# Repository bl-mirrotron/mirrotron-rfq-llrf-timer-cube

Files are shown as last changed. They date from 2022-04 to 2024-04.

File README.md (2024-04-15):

# RFQ LLRF Timer Cube
* <a href="https://github.com/bl-mirrotron/mirrotron-rfq-llrf-timer-cube" target="_blank">Source code</a>
* [RF frequency source](https://bl-mirrotron.github.io/mirrotron-rf-src-tray/)
* [Gate generator](https://bl-mirrotron.github.io/gateGen125-tray/)
* [Timing system overview](https://bl-mirrotron.github.io/#timing-system)
* [Control system overview](https://bl-mirrotron.github.io/)

The RFQ LLRF Timer Cube is a circuit card that mounts onto header connectors of a <a href="https://redpitaya.com/product-category/stemlab-125-14/" target="_blank">Red Pitaya Stemlab 125-14</a> computer  as shown in Figure 1.  The circuit is used both for the <a href="https://bl-mirrotron.github.io/mirrotron-rf-src-tray/">RF Frequency Source</a> and the <a href="https://bl-mirrotron.github.io/gateGen125-tray/">Gate Generator</a> for the <a href="https://bl-mirrotron.github.io/#timing-system">Timing system</a>. The card contains two systems that can be used independently.

The first system connects a <a href="https://www.mikroe.com/pll-click" target="_blank">PLL Click</a> 8x Phase Lock Loop card that is used by the RF Frequency Source to multiply the 12.5 MHz Direct Digital Synthesizer signal from the Red Pitaya Stemlab 125-14 to 100 MHz.

The second system generates TTL level signals from the Red Pitaya Stemlab 125-14 FPGA digital output pin header to eight SMA RF connectors for the Gate Generator  used in the Timing system.

The circuit also provides 5V and 3.3V output from the Red Pitaya Stemlab 125-14 that can be used to power auxiliary devices such as micro-fans or low noise amplifiers.

The schematic for the card is shown in Figure 2 and the PCB layout is shown in Figure 3.

<p style="text-align:center;font-size: large;"><span style="font-weight: bold;color: green;">Figure 1. </span> <span style="font-style: italic;">RFQ LLRF Timer Cube mounted on a Red Pitaya Stemlab 125-14</span></p>
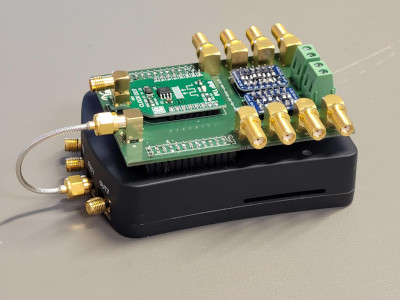
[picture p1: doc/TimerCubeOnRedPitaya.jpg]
<br>

<p style="text-align:center;font-size: large;"><span style="font-weight: bold;color: green;">Figure 2. </span> <span style="font-style: italic;">RFQ LLRF Timer Cube Schematic</span></p>
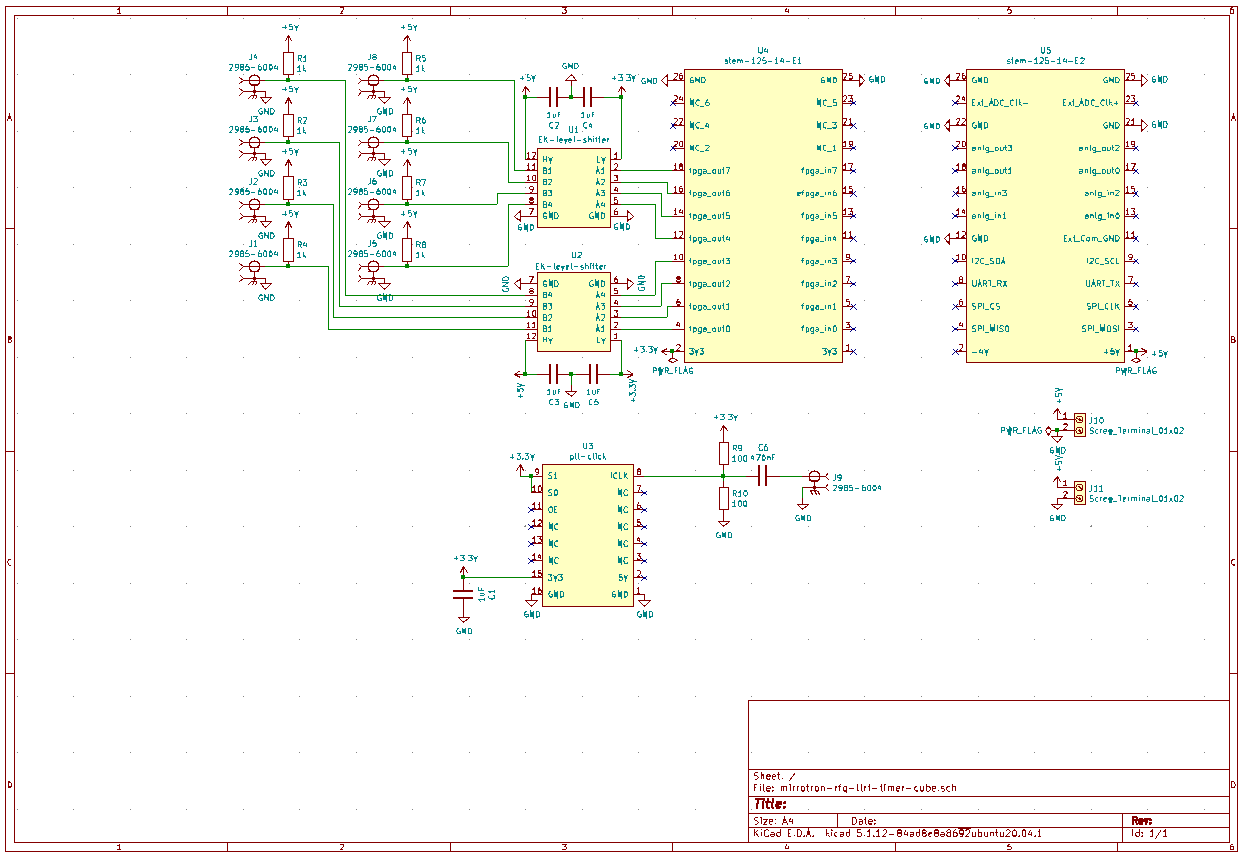
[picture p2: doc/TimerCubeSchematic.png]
<br>

<p style="text-align:center;font-size: large;"><span style="font-weight: bold;color: green;">Figure 3. </span> <span style="font-style: italic;">RFQ LLRF Timer Cube PCB layout</span></p>
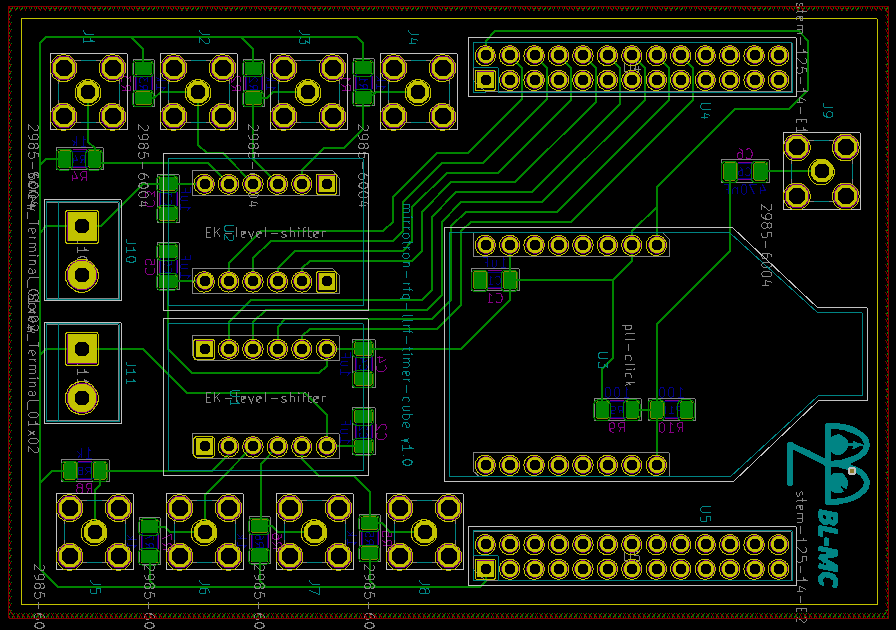
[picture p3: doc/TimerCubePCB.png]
<br>

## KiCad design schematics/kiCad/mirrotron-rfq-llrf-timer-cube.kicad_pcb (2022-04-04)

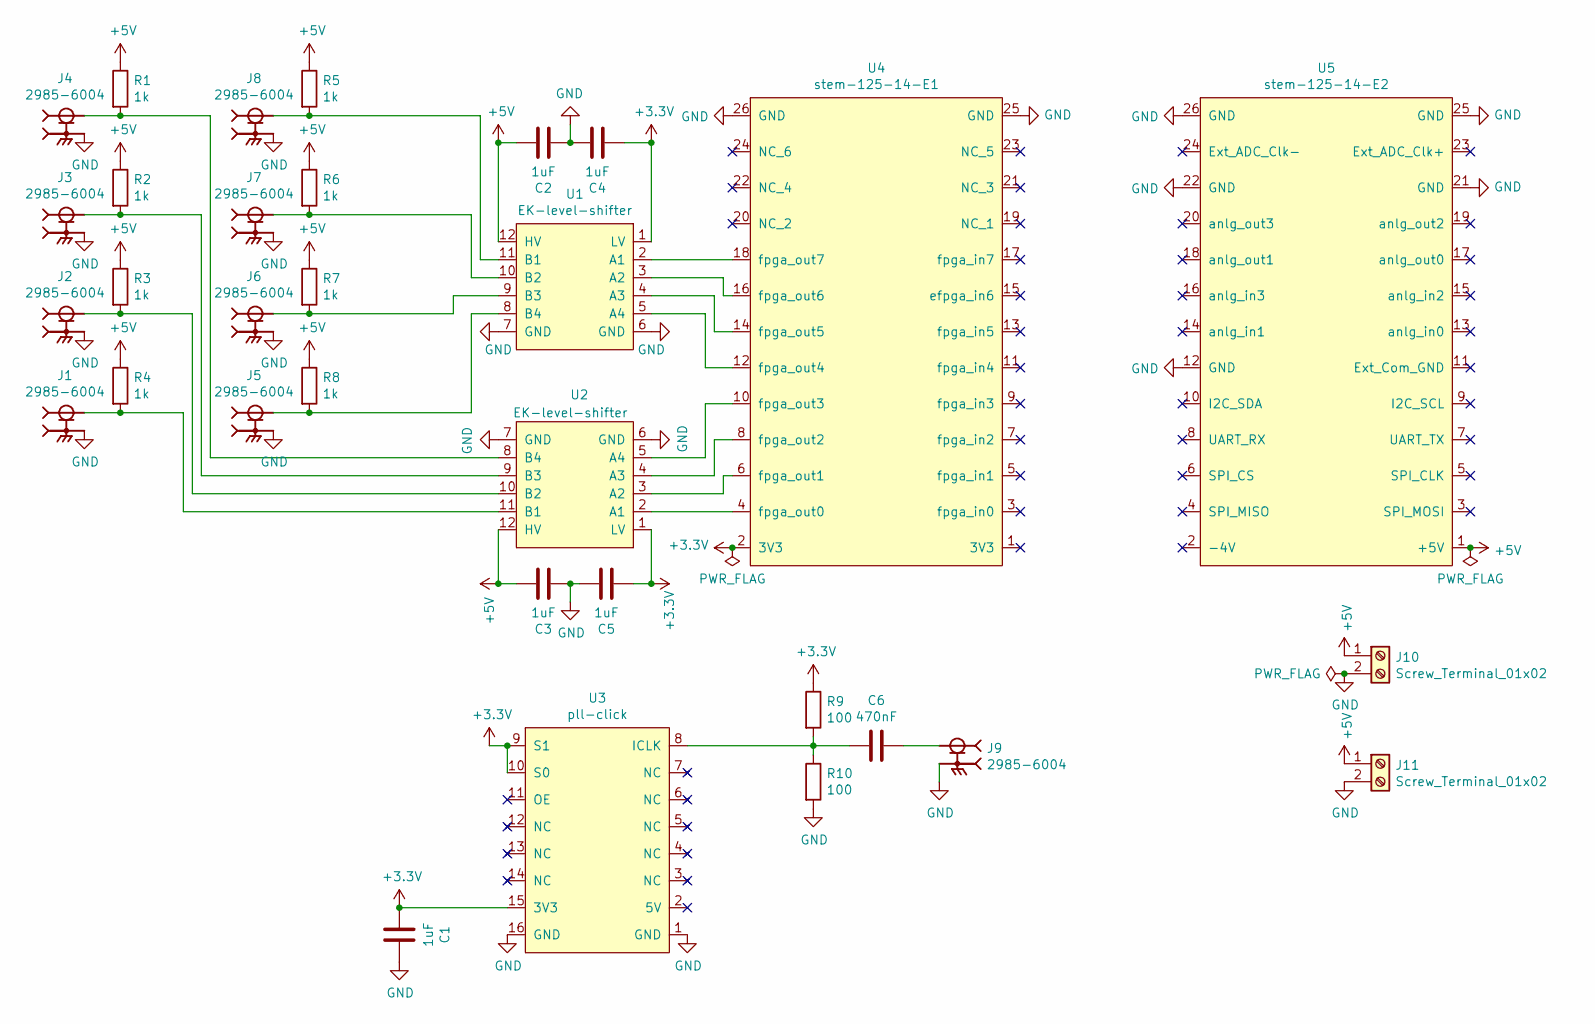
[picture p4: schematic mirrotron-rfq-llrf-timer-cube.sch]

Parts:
C1, C2, C3, C4, C5: 1uF; C_1206_3216Metric_Pad1.33x1.80mm_HandSolder
C6: 470nF; C_1206_3216Metric_Pad1.33x1.80mm_HandSolder
J1, J2, J3, J4, J5, J6, J7, J8, J9: 2985-6004; AMPHENOL_2985-6004
J10, J11: Screw_Terminal_01x02; TerminalBlock_bornier-2_P5.08mm
R1, R2, R3, R4, R5, R6, R7, R8: 1k; R_1206_3216Metric_Pad1.30x1.75mm_HandSolder
R9, R10: 100; R_1206_3216Metric_Pad1.30x1.75mm_HandSolder
U1, U2: EK-level-shifter
U3: pll-click
U4: stem-125-14-E1; red-pitaya-extender
U5: stem-125-14-E2; red-pitaya-extender

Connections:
+3V3: C1.2, C4.2, C5.2, R9.1, U1.1 (LV), U2.1 (LV), U3.9 (S1), U3.10 (S0), U3.15 (3V3), U4.2 (3V3)
+5V: C2.1, C3.1, J10.1, J11.1, R1.1, R2.1, R3.1, R4.1, R5.1, R6.1, R7.1, R8.1, U1.12 (HV), U2.12 (HV), U5.1 (+5V)
GND: C1.1, C2.2, C3.2, C4.1, C5.1, J1.S1, J1.S2, J1.S3, J1.S4, J2.S1, J2.S2, J2.S3, J2.S4, J3.S1, J3.S2, J3.S3, J3.S4, J4.S1, J4.S2, J4.S3, J4.S4, J5.S1, J5.S2, J5.S3, J5.S4, J6.S1, J6.S2, J6.S3, J6.S4, J7.S1, J7.S2, J7.S3, J7.S4, J8.S1, J8.S2, J8.S3, J8.S4, J9.S1, J9.S2, J9.S3, J9.S4, J10.2, J11.2, R10.2, U1.6 (GND), U1.7 (GND), U2.6 (GND), U2.7 (GND), U3.1 (GND), U3.16 (GND), U4.25 (GND), U4.26 (GND), U5.12 (GND), U5.21 (GND), U5.22 (GND), U5.25 (GND), U5.26 (GND)
unnamed: C6.1, J9.1
unnamed: C6.2, R9.2, R10.1, U3.8 (ICLK)
unnamed: J1.1, R4.2, U2.11 (B1)
unnamed: J2.1, R3.2, U2.10 (B2)
unnamed: J3.1, R2.2, U2.9 (B3)
unnamed: J4.1, R1.2, U2.8 (B4)
unnamed: J5.1, R8.2, U1.8 (B4)
unnamed: J6.1, R7.2, U1.9 (B3)
unnamed: J7.1, R6.2, U1.10 (B2)
unnamed: J8.1, R5.2, U1.11 (B1)
unnamed: U1.2 (A1), U4.18 (fpga_out7)
unnamed: U1.3 (A2), U4.16 (fpga_out6)
unnamed: U1.4 (A3), U4.14 (fpga_out5)
unnamed: U1.5 (A4), U4.12 (fpga_out4)
unnamed: U2.2 (A1), U4.4 (fpga_out0)
unnamed: U2.3 (A2), U4.6 (fpga_out1)
unnamed: U2.4 (A3), U4.8 (fpga_out2)
unnamed: U2.5 (A4), U4.10 (fpga_out3)

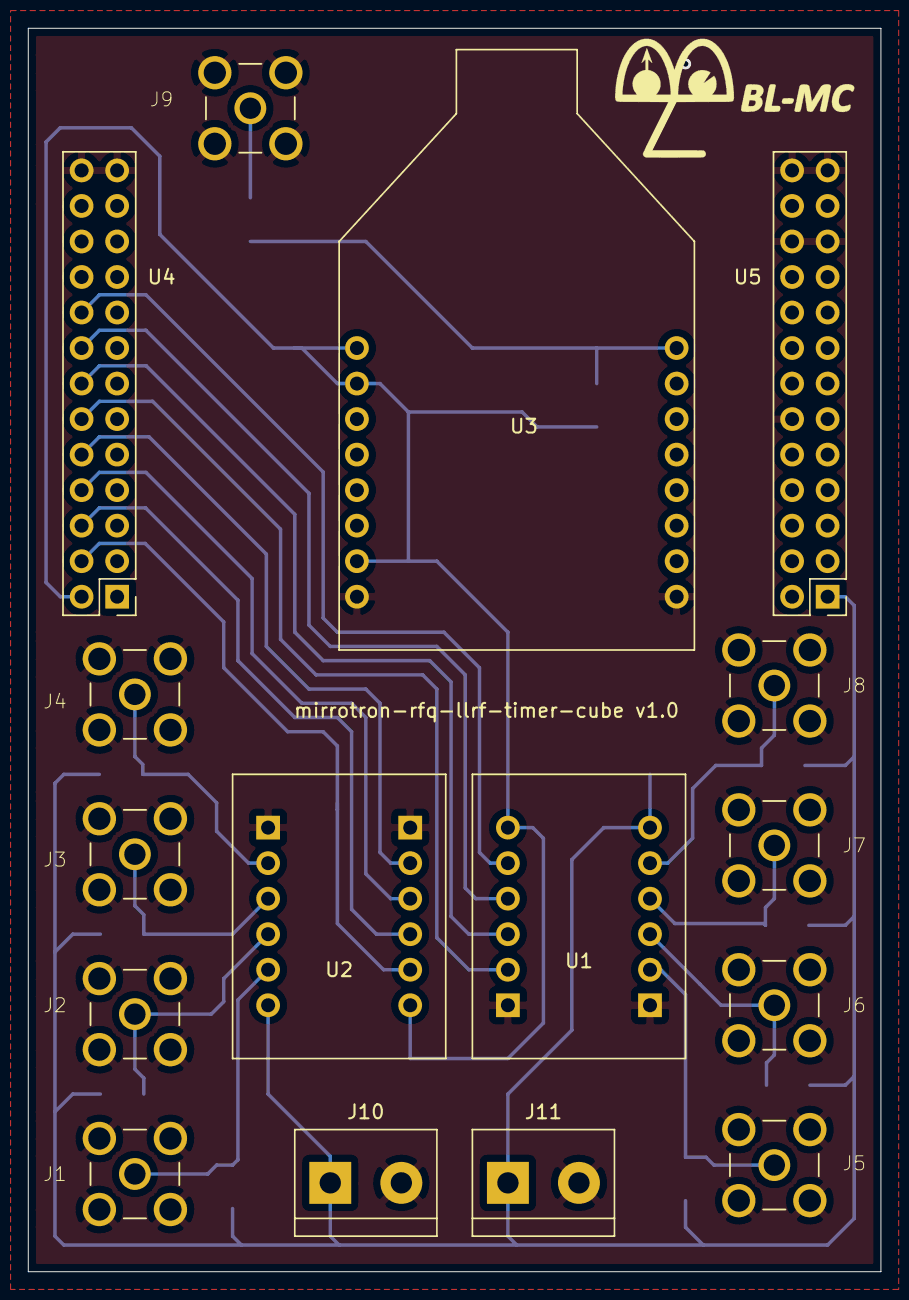
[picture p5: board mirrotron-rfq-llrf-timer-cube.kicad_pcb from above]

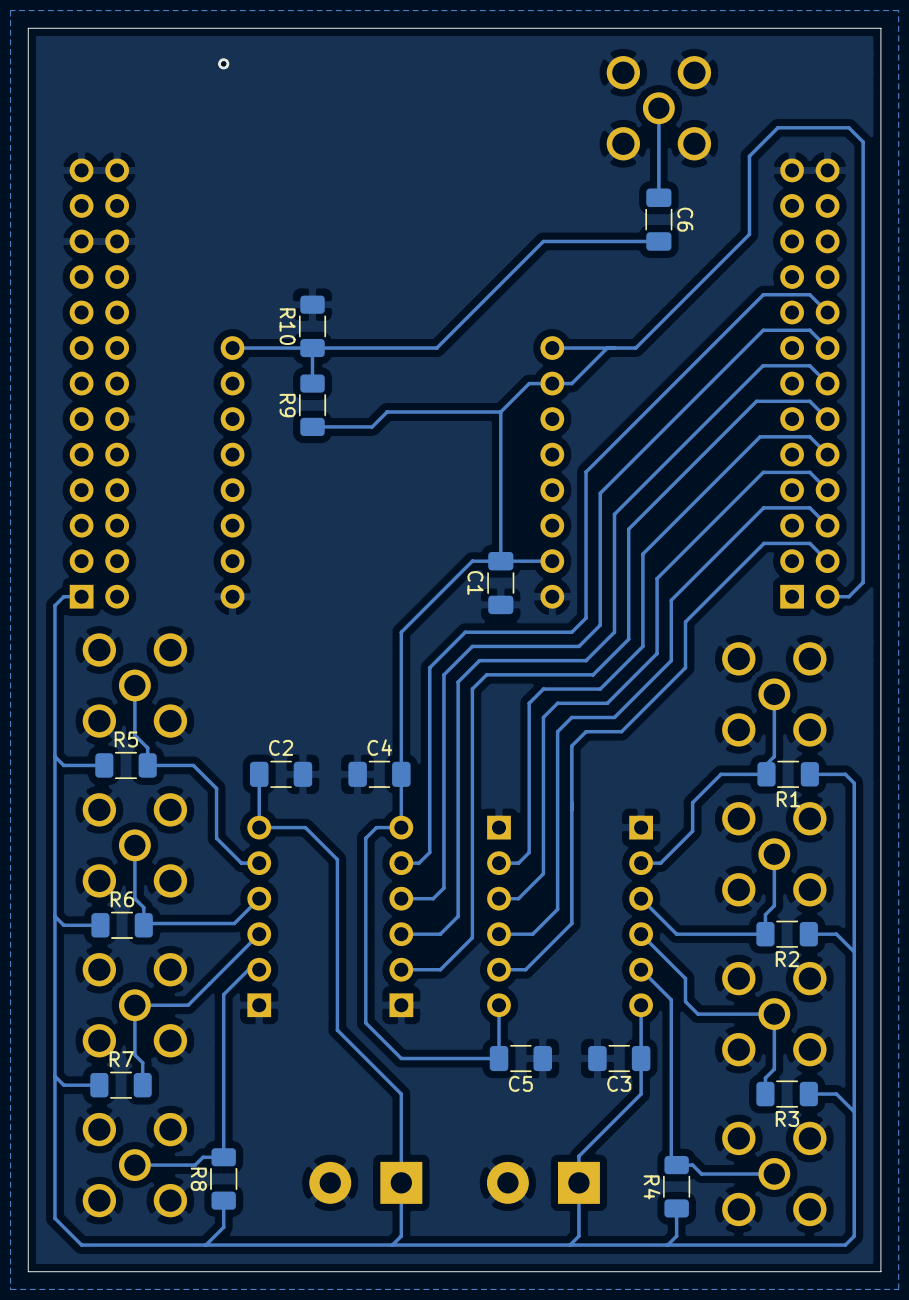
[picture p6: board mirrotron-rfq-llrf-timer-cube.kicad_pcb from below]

Board: 2 copper layers, 61.0 x 88.9 mm, 32 parts (16 on the bottom side), 21 nets.
